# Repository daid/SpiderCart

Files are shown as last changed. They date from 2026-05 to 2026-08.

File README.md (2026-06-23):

# SpiderCart

SpiderCart is a new gameboy and gameboy color flash cartridge. Which will have many legs over the alternatives.

Currently, it is still in development. But it uses a different setup compared to other flash carts. Other carts use FPGAs or CPLDs. Instead the SpiderCart uses a single RP2354B microcontroller to function as the MBC and handle all other functionalities required. This offers greater flexiblity at lower costs.

The SpiderCart is fully open source MIT license. And can be produced and copied by anyone. It also has all the flexibility to be modified by anyone.

## Terminology

This repository documents the technical side of the SpiderCart. Because of this it uses a lot of terminology. This list ensures that we all speak the same language.

* DMG: The origonal grey brick gameboy. With 4 "green" colors.
* GBC: The Gameboy Color. Upgraded version of the grey brick with color support, double CPU speed and a few more things.
* MCU: Microcontroller. In this case the RP2354B from Raspberry Pi. The RP2354B is a RP2350 with internal flash, so references to RP2350 are also refering to this chip.
* SRAM: "Save" ram. This is also called "external ram" from the gameboy perspective, and contained within the cartridge. Optionally this is preserved between power cycles. Not to be confused with "Static RAM" which is a name of a specific type of RAM chips (to which we just refer as RAM chip)
* RTC: A clock. The gameboy documentation usually refers to this as the Timer. It keep "clock"/"wall" time. Even when the gameboy is off. This requires a battery to preserve state.
* Firmware: Code installed on the MCU that facilitates the operation of the flash cart
* Loader: The code running on the gameboy that allows selecting of rom files and potentially do other things.

## Features

The following features are working:

* Support running DMG and GBC roms up to 2MB in size (V1 limitation, design supports up to 8MB)
* Saves backed up to SD card automatically
* Menu to load ROMs from SD card
* Directly loading ROMs through the USB port for quick ROM debugging/testing
* Optional quickboot to start a rom without resetting and running the bootrom (not compatible with all roms)

The following features are in development:

* Pico-8 support
* USB port direct access to SD card for easy file updating without taking out the SD card
* Full support for RTC (Harvest Moon / Pokemon / Homebrew)
* 3 axis accelerometer (Kirby's Tilt 'n' Tumble / Homebrew)
* Rumble support

The following features are ideas that could work but not actively being developed right now:

* Customizable loader to make rom selection look how you want it, current loader is ugly but functional
* SD file access for homebrew
* USB networking
* NES emulation
* Doom

## Implementation

The SpiderCart is implemented by connecting the MCU and RAM chip directly to the gameboy cartridge bus. The RAM chip is loaded with whatever ROM needs to run. The rom is loaded by the MCU into the RAM chip, this can be done while the gameboy is kept in reset.

While the gameboy is running, the MCU needs to act like the MBC, controlling when the RAM chip is enabled, as well as simulating the SRAM. It will only need of the two CPU cores this MCU has, so 1 will be available for other functionality.

On the 150Mhz RP2350 Core1 is constantly running as MBC, while core0 handles things like saving SRAM and communicating with the RTC/Accelerometer/USB.

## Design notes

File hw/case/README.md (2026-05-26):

https://www.printables.com/model/215698-gameboy-cartridge

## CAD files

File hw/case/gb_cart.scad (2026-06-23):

// Gameboy Cartridge
//
// By: Dave Parker https://www.printables.com/social/175295-dave/about
//
// Print with build plate supports, 0.2mm layer height
//

include <BOSL/shapes.scad> // https://github.com/revarbat/BOSL

$fa = 1;
$fs = .1;
ff = 0.001; // fudge factor

width = 57;
depth = 64.8;

classic = false; // Whether to include a logo area on the top half

// fit test with top and bottom interlocking
// translate([0, 0, total_top_height + bottom_base_height + 1.8 ])rotate([0, 180, 0]) top();
// bottom();

// normal rendering
translate([-width/2 - 1, 0, 0]) top();
translate([width/2 + 1, 0, 0]) bottom();

translate([width/2 + 1, depth/2-0.7, 1.6]) % color("#ff000080") import("../pcb/SpiderCart.stl");
translate([-width/2 - 1, depth/2-0.7, 5.8]) rotate([0,180,0]) % color("#ff000080") import("../pcb/SpiderCart.stl");

//translate([-width/2 - 1, 0, 0]) color("#ff00ff") label_cutout();


// BOTTOM HALF /////////////////////////////////////////////////////////////////

alignment_post_height = 2;
alignment_post_r = 0.9;
alignment_post_y = 41.9;

bottom_base_height = 1.4;
bottom_wall_thickness = 1.8;
bottom_wall_height = 4.3;

far_notch_width = 2.5;
far_notch_depth = 1.2;
far_notch_height = 2.5;

groove_height = 1.4;
groove_width = 1.4;

lock_depth = 3;
lock_height = 3;
lock_travel = 2;
lock_width = 1;
lock_y_near = 11;
lock_y_far = 50;

pcb_screw_post_height = 1.6;
pcb_screw_post_r = 3.7;

ridge_depth = 0.8;
ridge_height = 0.2;
ridge_width = 50;

screw_head_height = 2;
screw_head_radius = 3.0;
screw_hole_passthrough_r = 2.0;
screw_y = 17;

type_notch_depth = 3;
type_notch_width = 5;

groove_depth = lock_y_near;
lock_entrance_height = bottom_wall_height - lock_height;
total_bottom_base_height = bottom_base_height + bottom_wall_height;

module usb_hole() {
    cube([10, 10, 4], center=true);
    rotate([90,0,0]) linear_extrude(7, center=true) hull() {
        translate([ 4,-1.5]) circle(2);
        translate([-4,-1.5]) circle(2);
        translate([ 4, 1.5]) circle(2);
        translate([-4, 1.5]) circle(2);
    }
}

module bottom() {

    difference() { 
        union() {
            bottom_base();
            bottom_far_wall();
            bottom_right_wall();
            bottom_left_wall();
        }
        
        if(classic) {
            bottom_grip(classic_grip_y, classic_grip_count);
        } else {
            bottom_grip(grip_y, grip_count);
        }
        translate([-18, 67, 4]) usb_hole();
        translate([-2, 67, 4]) cube([14, 10, 4.0], center=true);
    }
}


module bottom_base() {
    
    difference() { 
        union() {
            
            // Base minus notch at far end
            translate([-width/2, 0, 0])
                cuboid([width, depth - type_notch_depth + ff, bottom_base_height], fillet=0.5,
                    edges=EDGE_BK_RT+EDGE_BOT_LF+EDGE_BOT_RT, center=false);

            // Bit shorter at far end due to type notch
            translate([-width/2, depth - type_notch_depth - ff, 0])
                      cuboid([width - type_notch_width, type_notch_depth, bottom_base_height], fillet=0.5,
                      edges=EDGE_BK_RT+EDGE_BK_LF+EDGE_BOT_LF+EDGE_BOT_BK+EDGE_BOT_RT, center=false);
            
            // Ridge along inside bottom
            translate([-ridge_width/2, 0, bottom_base_height - ff])
                cube([ridge_width, ridge_depth, ridge_height]);
            
            // PCB screw post
            translate([0, screw_y, bottom_base_height - ff])
                cylinder(h=pcb_screw_post_height, r=pcb_screw_post_r);
            
            // Alignment post
            translate([0, alignment_post_y, bottom_base_height - ff])
                cylinder(h=alignment_post_height, r=alignment_post_r);
        }

        side_groove();  // Right
        mirror([-1, 0, 0]) side_groove(); // Left
        
        // Screw shaft hole
        translate([0, screw_y, - ff])
            cylinder(h=bottom_base_height + pcb_screw_post_height + ff*2, r=screw_hole_passthrough_r);

        // Screw thread hole
        translate([0, screw_y, - ff])
            cylinder(h=screw_head_height + ff*2, r=screw_head_radius);

    }
}


module bottom_grip(y, count) {
    
    for(i=[1:1:count]) {
        
        dy = y + i*(grip_thickness + grip_spacing);

         translate([-width/2 - ff, dy, - ff])
             cube([grip_side_depth, grip_thickness, total_bottom_base_height  + ff*2]);
        
         translate([width/2 - grip_side_depth + ff , dy, - ff])
             cube([grip_side_depth, grip_thickness, total_bottom_base_height + ff*2]);
    }
}


module side_groove() {
    translate([ridge_width/2, - ff, groove_height/2 + ff]) 
        cube([groove_width, groove_depth, groove_height/2 + ff*2]);
}


module bottom_right_wall() {  

    difference() {
        union() {
            translate([width/2 - bottom_wall_thickness, 0, bottom_base_height - ff])
                cuboid([bottom_wall_thickness, depth - type_notch_depth, bottom_wall_height],
                        fillet=0.5, edges=EDGE_BK_RT, center=false);

            bottom_wall_common_additive();
        }

        bottom_wall_common_subtractive();
    }
}


module bottom_left_wall() {  

    difference() {
        union() {
            translate([-width/2, 0, bottom_base_height - ff])
                cube([bottom_wall_thickness, depth - bottom_wall_thickness + ff, bottom_wall_height]);
            
            mirror([-1, 0, 0]) bottom_wall_common_additive();
        }
        
        mirror([-1, 0, 0]) bottom_wall_common_subtractive();
    }
}


module bottom_wall_common_additive() {
    
    dx = width/2 - bottom_wall_thickness - (ridge_width/2 + groove_width) + ff;
    translate([ridge_width/2 + groove_width, 0, bottom_base_height - ff])
        cube([dx, groove_depth, bottom_wall_height]);
}


module bottom_wall_common_subtractive() {
    lock(lock_y_near);
    lock(lock_y_far);
}


module lock(y) {
    
    // Entrance
    translate([width/2 - bottom_wall_thickness - ff, y, bottom_base_height - ff])
        cube([lock_width, lock_depth, bottom_wall_height + ff*2]);
    
    // Travel
    translate([width/2 - bottom_wall_thickness - ff, y + lock_depth - ff, bottom_base_height - ff])
        cube([lock_width, lock_travel, lock_height + ff*2]); 
}


module bottom_far_wall() {
    
    difference() {
        // Far wall
        translate([-width/2, depth - bottom_wall_thickness, bottom_base_height - ff])
            cuboid([width - type_notch_width, bottom_wall_thickness, bottom_wall_height],
            fillet=0.5, edges=EDGE_BK_LF+EDGE_BK_RT, center=false);
        
        // Far wall notch
        translate([-far_notch_width/2, depth - bottom_wall_thickness - ff, bottom_base_height - ff])
            cube([far_notch_width, far_notch_depth, far_notch_height]);
    }
 
    // Mode notch horizontal wall
    translate([width/2 - bottom_wall_thickness - type_notch_width + ff,
              depth - bottom_wall_thickness - type_notch_depth,
              bottom_base_height - ff])
        cube([type_notch_width, bottom_wall_thickness,  bottom_wall_height]);
    
    // Mode notch vertical wall
    translate([width/2 - bottom_wall_thickness - type_notch_width + ff,
              depth - bottom_wall_thickness - type_notch_depth,
              bottom_base_height - ff])
        cube([bottom_wall_thickness, type_notch_depth,  bottom_wall_height]);
}


// TOP HALF /////////////////////////////////////////////////////////////////////

far_tab_width = far_notch_width - 0.5;
far_tab_depth = far_notch_depth - 0.2;
far_tab_height = far_notch_height/2; 

classic_grip_count = 5;

grip_count = 6;
grip_side_depth = 0.3;
grip_top_depth = 0.6;
grip_thickness = 1;
grip_spacing = 1;

key_depth = lock_depth - 1;
key_width = lock_width - 0.2;

label_depth = 39;
label_height = 0.2;
label_y = 8;
label_width = 44;

logo_depth = 12;
logo_height = 0.6;
logo_width = 44;
logo_y = label_y + label_depth + 2;

screw_height = 3;
screw_hole_thread_r = 1.45;
screw_shaft_r = 3;

side_tab_y = 32;
side_tab_width = 1.5;
side_tab_depth = 1;

top_angle_cut_depth = 37.7;
top_height = 2;
top_inner_height = 1.3;
top_near_wall_y = 10;
top_wall_height = 3.8;
top_wall_thickness = 1.5;

wall_gap = 0.4; // Padding between top and bottom walls

grip_y = label_y + label_depth;
classic_grip_y = grip_y + 1.5;
key_height = top_wall_height - lock_entrance_height - 0.75;
total_top_height = top_height - top_inner_height + top_wall_height;
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

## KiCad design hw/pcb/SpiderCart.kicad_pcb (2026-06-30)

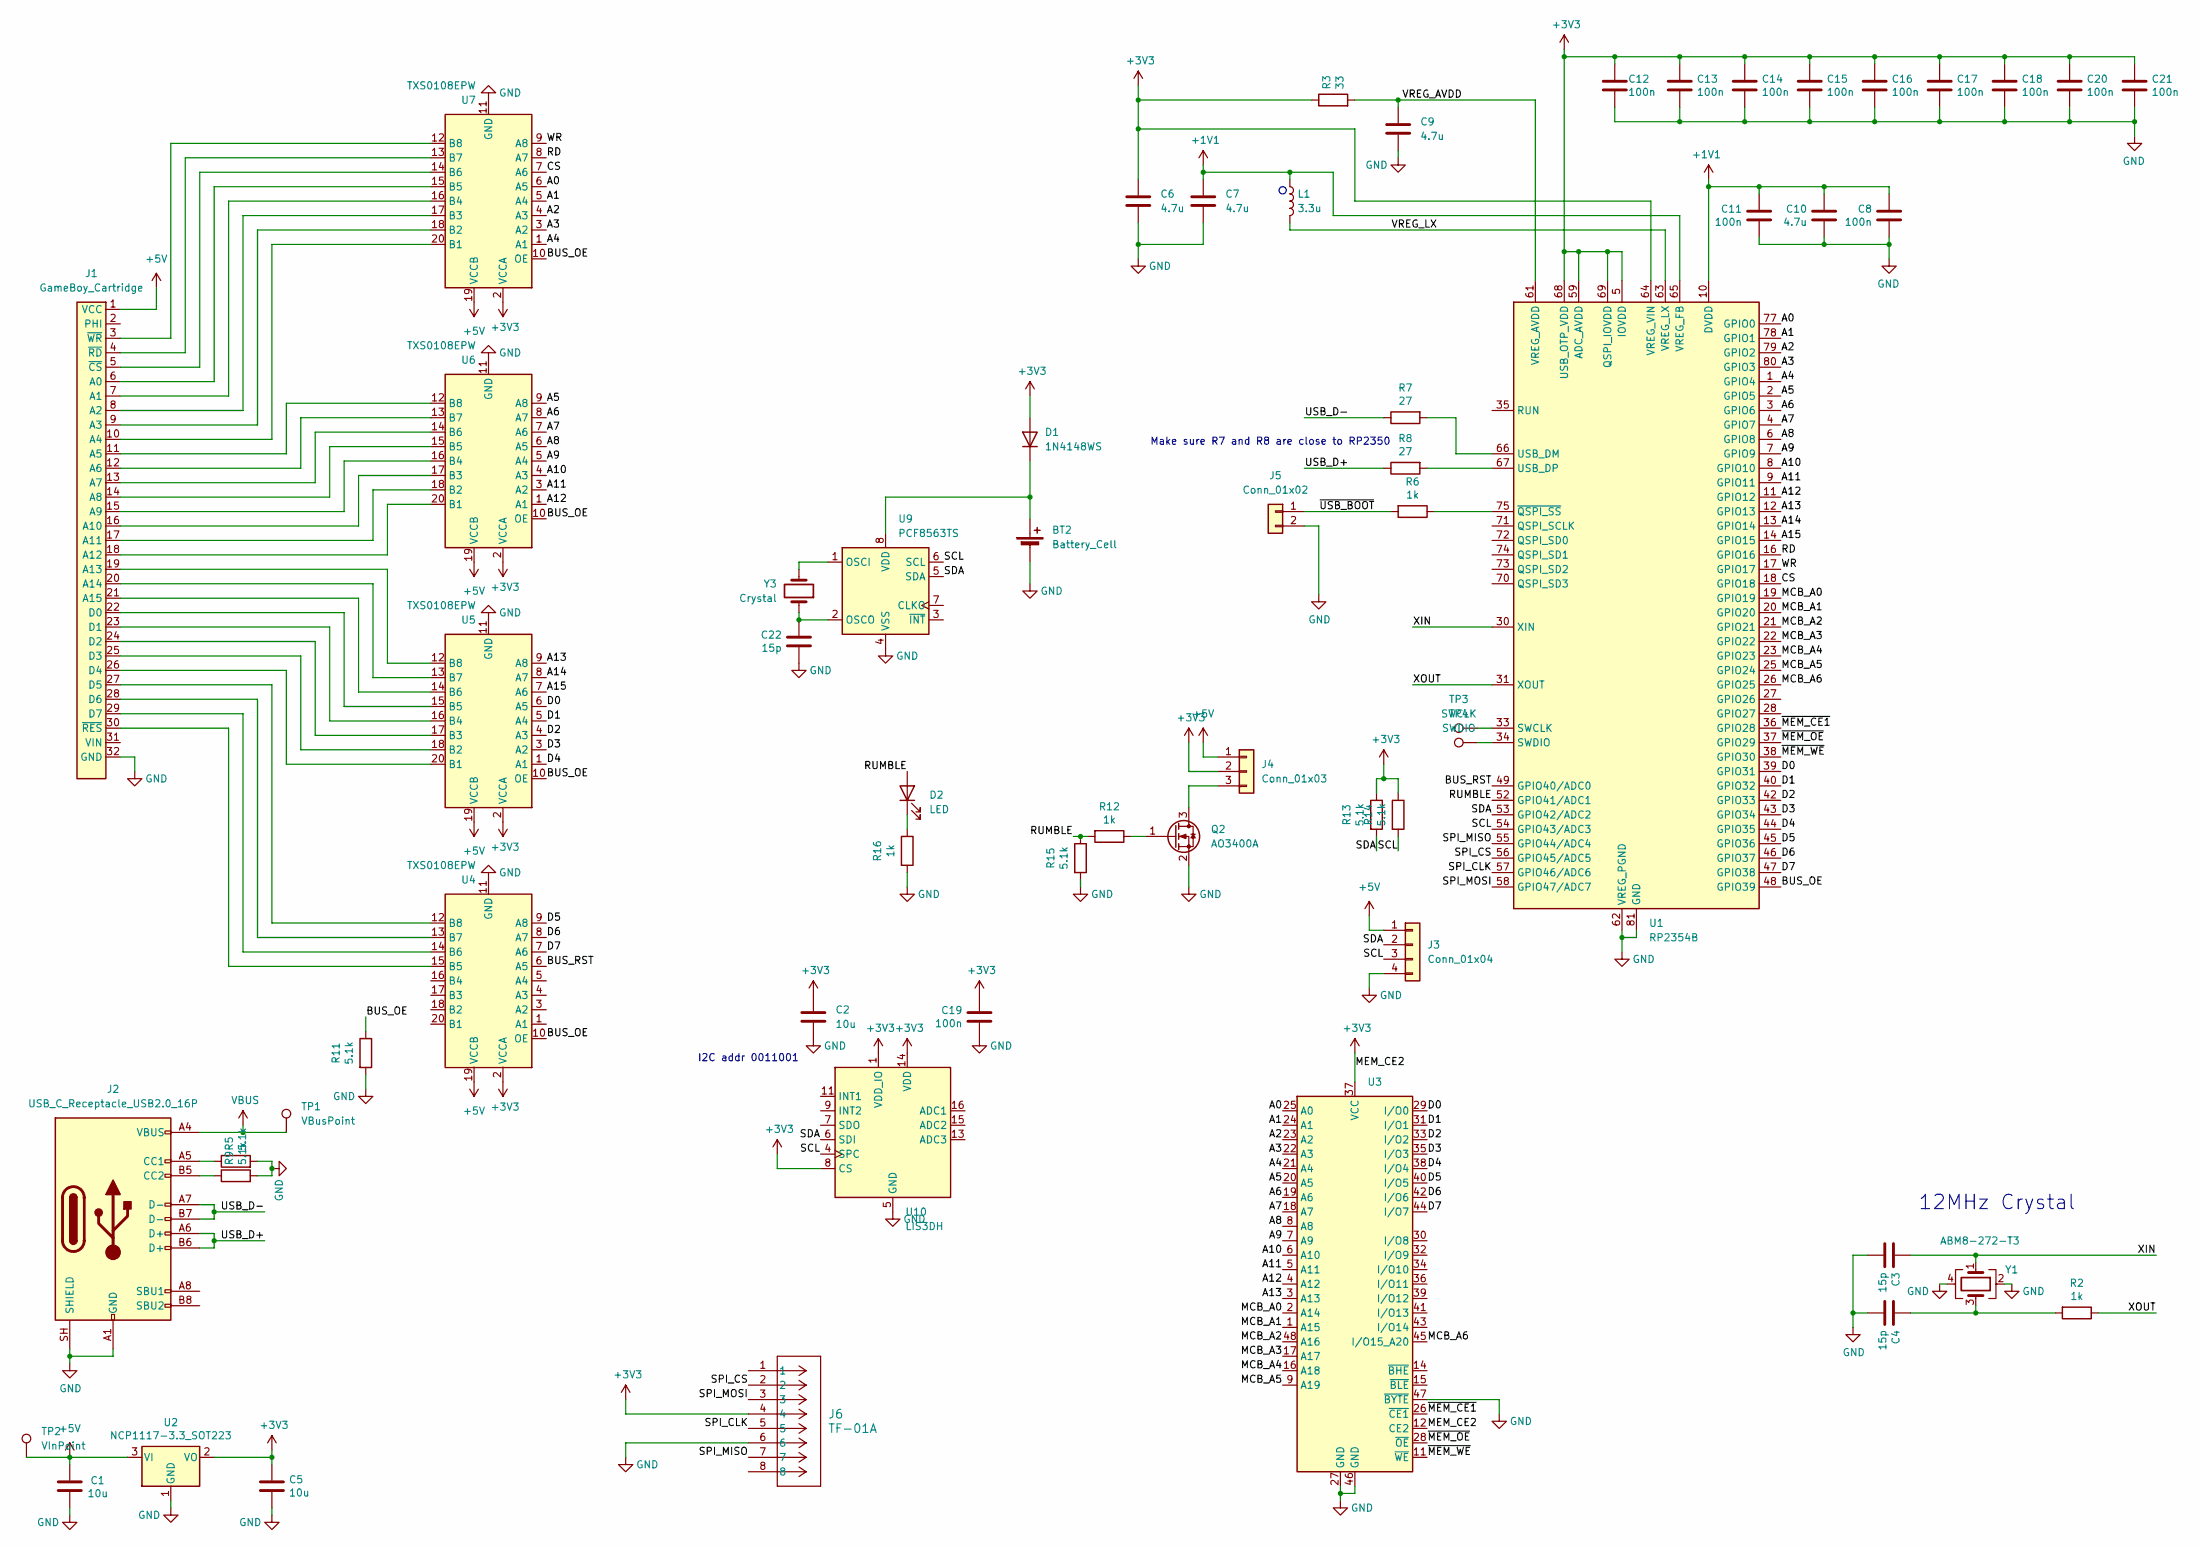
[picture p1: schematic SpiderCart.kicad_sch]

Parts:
BT2: Battery_Cell; BatteryHolder_Keystone_2998_1x6.8mm
C1, C5: 10u; C_0805_2012Metric
C2: 10u; C_0402_1005Metric
C3, C4, C22: 15p; C_0402_1005Metric
C6, C7: 4.7u; C_0402_1005Metric_small_pads
C8, C11, C12, C13, C14, C15, C16, C17, C18, C19, C20, C21: 100n; C_0402_1005Metric
C9, C10: 4.7u; C_0402_1005Metric
D1: 1N4148WS; D_SOD-323
D2: LED; LED_0603_1608Metric
J1: GameBoy_Cartridge; GameBoy_Cartridge_1x32_P1.50mm_Edge
J2: USB_C_Receptacle_USB2.0_16P; USB_C_Receptacle_JAE_DX07S016JA1R1500
J3: Conn_01x04; PinHeader_1x04_P1.27mm_Vertical
J4: Conn_01x03; PinHeader_1x03_P1.27mm_Vertical
J5: Conn_01x02; PinSocket_1x02_P1.27mm_Vertical
J6: TF-01A; CONN_TF-01A_HRO
L1: 3.3u; L_pol_2016
Q2: AO3400A; SOT-23
R2, R6, R12, R16: 1k; R_0402_1005Metric
R3: 33; R_0402_1005Metric
R5, R9, R11, R13, R14, R15: 5.1k; R_0402_1005Metric
R7, R8: 27; R_0402_1005Metric
TP1: VBusPoint; PinHeader_1x01_P1.27mm_Vertical
TP2: VInPoint; PinHeader_1x01_P1.27mm_Vertical
TP3: SWCLK; TestPoint_Pad_D1.5mm
TP4: SWDIO; TestPoint_Pad_D1.5mm
U1: RP2354B; QFN-80-1EP_10x10mm_P0.4mm_EP3.4x3.4mm_ThermalVias
U2: NCP1117-3.3_SOT223; SOT-223-3_TabPin2
U3: TSOP-I-48_18.4x12mm_P0.5mm
U4, U5, U6, U7: TXS0108EPW; TSSOP-20_4.4x6.5mm_P0.65mm
U9: PCF8563TS; MSOP-8_3x3mm_P0.65mm
U10: LIS3DH; LGA-16_3x3mm_P0.5mm_LayoutBorder3x5y
Y1: ABM8-272-T3; Crystal_SMD_3225-4Pin_3.2x2.5mm
Y3: Crystal; Crystal_SMD_3215-2Pin_3.2x1.5mm

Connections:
+1V1: C7.1, C8.1, C10.1, C11.1, L1.1, U1.10 (DVDD), U1.32 (DVDD), U1.51 (DVDD), U1.65 (VREG_FB)
+3V3: C2.1, C5.1, C6.1, C12.1, C13.1, C14.1, C15.1, C16.1, C17.1, C18.1, C19.1, C20.1, C21.1, D1.2 (A), J4.2, J6.4, R3.1, R13.1, R14.1, U1.5 (IOVDD), U1.15 (IOVDD), U1.24 (IOVDD), U1.29 (IOVDD), U1.41 (IOVDD), U1.50 (IOVDD), U1.59 (ADC_AVDD), U1.60 (IOVDD), U1.64 (VREG_VIN), U1.68 (USB_OTP_VDD), U1.69 (QSPI_IOVDD), U1.76 (IOVDD), U2.2 (VO), U3.12 (CE2), U3.37 (VCC), U4.2 (VCCA), U5.2 (VCCA), U6.2 (VCCA), U7.2 (VCCA), U10.1 (VDD_IO), U10.8 (CS), U10.14 (VDD)
+5V: C1.1, J1.1 (VCC), J3.1, J4.1, TP2.1 (1_1), U2.3 (VI), U4.19 (VCCB), U5.19 (VCCB), U6.19 (VCCB), U7.19 (VCCB)
/A0: U1.77 (GPIO0), U3.25 (A0), U7.6 (A5)
/A1: U1.78 (GPIO1), U3.24 (A1), U7.5 (A4)
/A2: U1.79 (GPIO2), U3.23 (A2), U7.4 (A3)
/A3: U1.80 (GPIO3), U3.22 (A3), U7.3 (A2)
/A4: U1.1 (GPIO4), U3.21 (A4), U7.1 (A1)
/A5: U1.2 (GPIO5), U3.20 (A5), U6.9 (A8)
/A6: U1.3 (GPIO6), U3.19 (A6), U6.8 (A7)
/A7: U1.4 (GPIO7), U3.18 (A7), U6.7 (A6)
/A8: U1.6 (GPIO8), U3.8 (A8), U6.6 (A5)
/A9: U1.7 (GPIO9), U3.7 (A9), U6.5 (A4)
/A10: U1.8 (GPIO10), U3.6 (A10), U6.4 (A3)
/A11: U1.9 (GPIO11), U3.5 (A11), U6.3 (A2)
/A12: U1.11 (GPIO12), U3.4 (A12), U6.1 (A1)
/A13: U1.12 (GPIO13), U3.3 (A13), U5.9 (A8)
/A14: U1.13 (GPIO14), U5.8 (A7)
/A15: U1.14 (GPIO15), U5.7 (A6)
/BUS_OE: R11.1, U1.48 (GPIO39), U4.10 (OE), U5.10 (OE), U6.10 (OE), U7.10 (OE)
/BUS_RST: U1.49 (GPIO40/ADC0), U4.6 (A5)
/CS: U1.18 (GPIO18), U7.7 (A6)
/D0: U1.39 (GPIO31), U3.29 (I/O0), U5.6 (A5)
/D1: U1.40 (GPIO32), U3.31 (I/O1), U5.5 (A4)
/D2: U1.42 (GPIO33), U3.33 (I/O2), U5.4 (A3)
/D3: U1.43 (GPIO34), U3.35 (I/O3), U5.3 (A2)
/D4: U1.44 (GPIO35), U3.38 (I/O4), U5.1 (A1)
/D5: U1.45 (GPIO36), U3.40 (I/O5), U4.9 (A8)
/D6: U1.46 (GPIO37), U3.42 (I/O6), U4.8 (A7)
/D7: U1.47 (GPIO38), U3.44 (I/O7), U4.7 (A6)
/MCB_A0: U1.19 (GPIO19), U3.2 (A14)
/MCB_A1: U1.20 (GPIO20), U3.1 (A15)
/MCB_A2: U1.21 (GPIO21), U3.48 (A16)
/MCB_A3: U1.22 (GPIO22), U3.17 (A17)
/MCB_A4: U1.23 (GPIO23), U3.16 (A18)
/MCB_A5: U1.25 (GPIO24), U3.9 (A19)
/MCB_A6: U1.26 (GPIO25), U3.45 (I/O15_A20)
/RD: U1.16 (GPIO16), U7.8 (A7)
/RUMBLE: D2.2 (A), R12.2, R15.1, U1.52 (GPIO41/ADC1)
/SCL: J3.3, R14.2, U1.54 (GPIO43/ADC3), U9.6 (SCL), U10.4 (SPC)
/SDA: J3.2, R13.2, U1.53 (GPIO42/ADC2), U9.5 (SDA), U10.6 (SDI)
/SPI_CLK: J6.5, U1.57 (GPIO46/ADC6)
/SPI_CS: J6.2, U1.56 (GPIO45/ADC5)
/SPI_MISO: J6.7, U1.55 (GPIO44/ADC4)
/SPI_MOSI: J6.3, U1.58 (GPIO47/ADC7)
/USB_D+: J2.A6 (D+), J2.B6 (D+), R8.1
/USB_D-: J2.A7 (D-), J2.B7 (D-), R7.1
/VREG_AVDD: C9.1, R3.2, U1.61 (VREG_AVDD)
/VREG_LX: L1.2, U1.63 (VREG_LX)
/WR: U1.17 (GPIO17), U7.9 (A8)
/XIN: C3.1, U1.30 (XIN), Y1.1
/XOUT: R2.1, U1.31 (XOUT)
/~MEM_CE1: U1.36 (GPIO28), U3.26 (~CE1)
/~MEM_OE: U1.37 (GPIO29), U3.28 (~OE)
/~MEM_WE: U1.38 (GPIO30), U3.11 (~WE)
/~USB_BOOT: J5.1, R6.2
GND: BT2.2 (-), C1.2, C2.2, C3.2, C4.2, C5.2, C6.2, C7.2, C8.2, C9.2, C10.2, C11.2, C12.2, C13.2, C14.2, C15.2, C16.2, C17.2, C18.2, C19.2, C20.2, C21.2, C22.2, J1.32 (GND), J2.A1 (GND), J2.A12 (GND), J2.B1 (GND), J2.B12 (GND), J2.SH (SHIELD), J3.4, J5.2, J6.6, Q2.2 (S), R5.2, R9.2, R11.2, R15.2, R16.2, U1.62 (VREG_PGND), U1.81 (GND), U2.1 (GND), U3.27 (GND), U3.46 (GND), U3.47 (~BYTE), U4.11 (GND), U5.11 (GND), U6.11 (GND), U7.11 (GND), U9.4 (VSS), U10.5 (GND), U10.10 (GND), U10.12 (GND), Y1.2, Y1.4
unnamed: BT2.1 (+), D1.1 (K), U9.8 (VDD)
unnamed: C4.1, R2.2, Y1.3
unnamed: D2.1 (K), R16.1
unnamed: J1.6 (A0), U7.15 (B5)
unnamed: J1.7 (A1), U7.16 (B4)
unnamed: J1.8 (A2), U7.17 (B3)
unnamed: J1.9 (A3), U7.18 (B2)
unnamed: J1.10 (A4), U7.20 (B1)
unnamed: J1.11 (A5), U6.12 (B8)
unnamed: J1.12 (A6), U6.13 (B7)
unnamed: J1.13 (A7), U6.14 (B6)
unnamed: J1.14 (A8), U6.15 (B5)
unnamed: J1.15 (A9), U6.16 (B4)
unnamed: J1.16 (A10), U6.17 (B3)
unnamed: J1.17 (A11), U6.18 (B2)
unnamed: J1.18 (A12), U6.20 (B1)
unnamed: J1.19 (A13), U5.12 (B8)
unnamed: J1.20 (A14), U5.13 (B7)
unnamed: J1.21 (A15), U5.14 (B6)
unnamed: J1.22 (D0), U5.15 (B5)
unnamed: J1.23 (D1), U5.16 (B4)
unnamed: J1.24 (D2), U5.17 (B3)
unnamed: J1.25 (D3), U5.18 (B2)
unnamed: J1.26 (D4), U5.20 (B1)
unnamed: J1.27 (D5), U4.12 (B8)
unnamed: J1.28 (D6), U4.13 (B7)
unnamed: J1.29 (D7), U4.14 (B6)
unnamed: J1.5 (~CS), U7.14 (B6)
unnamed: J1.4 (~RD), U7.13 (B7)
unnamed: J1.30 (~RES), U4.15 (B5)
unnamed: J1.3 (~WR), U7.12 (B8)
unnamed: J2.A5 (CC1), R5.1
unnamed: J2.B5 (CC2), R9.1
unnamed: J4.3, Q2.3 (D)
unnamed: Q2.1 (G), R12.1
unnamed: TP3.1 (1_1), U1.33 (SWCLK)
unnamed: TP4.1 (1_1), U1.34 (SWDIO)
unnamed: R7.2, U1.66 (USB_DM)
unnamed: R8.2, U1.67 (USB_DP)
unnamed: R6.1, U1.75 (~QSPI_SS)
unnamed: U9.1 (OSCI), Y3.2
unnamed: C22.1, U9.2 (OSCO), Y3.1
VBUS: J2.A4 (VBUS), J2.A9 (VBUS), J2.B4 (VBUS), J2.B9 (VBUS), TP1.1 (1_1)

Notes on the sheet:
12MHz Crystal
Make sure R7 and R8 are close to RP2350
I2C addr 0011001

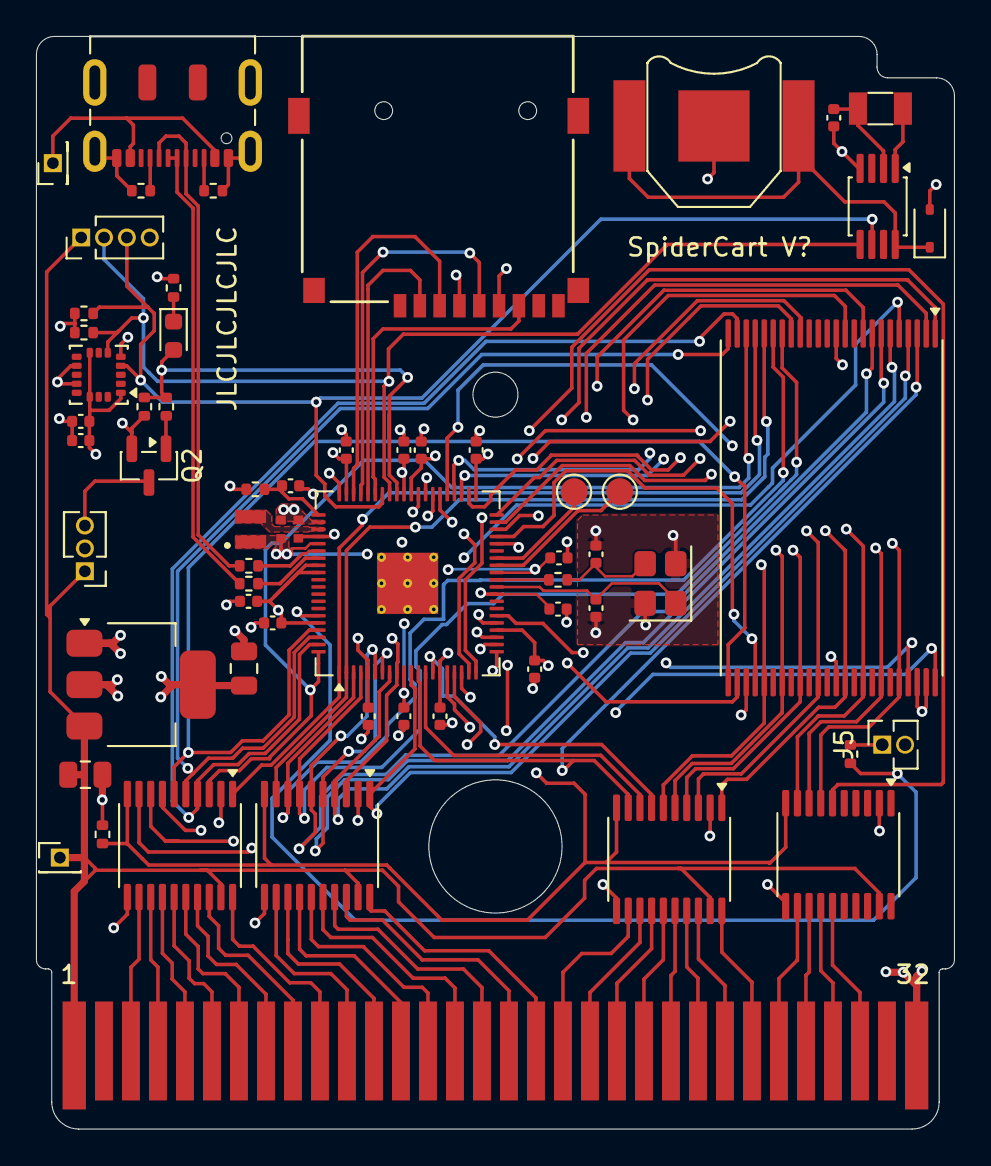
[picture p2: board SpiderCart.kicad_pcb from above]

Board: 4 copper layers, 51.0 x 60.7 mm, 61 parts (0 on the bottom side), 100 nets.

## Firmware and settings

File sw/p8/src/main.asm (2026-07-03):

#INCLUDE "gbz80/all.asm"
#INCLUDE "gbz80/extra/if.asm"
#INCLUDE "gbz80/extra/loop.asm"
#INCLUDE "gbz80/extra/ld16.asm"
#INCLUDE "gbz80/extra/pushpop.asm"

#INCLUDE "video.asm"
#INCLUDE "input.asm"
#INCLUDE "copy.asm"

#INCSDCC "config.rel"

GBC_HEADER "SpiderCart", GB_MBC5_RAM, entry

#SECTION "SpiderCartIndicator", ROM0[$150] {
    ; Most ROMs have the entry directly after the header. For a SpiderCart compatible ROM
    ; We put a special indicator here to indicate to the cart should run with special features enabled
    db $DD ; Indicator 1, this is an invalid instruction.
    db "SPIDER"
}

#SECTION "HRAM", HRAM {
hLCDC: ds 1
hVBlankDone: ds 1
hGBC: ds 1
}

#MACRO POPSLIDE {
    ld  [hl+],a
    ld  a, d
    ld  [hl+], a
    pop de
    ld  a, e
}

#MACRO HALT_FOR _FLAG {
    ld   a, _FLAG
    ldh  [rIE], a
    xor  a
    ldh  [rIF], a
    ld   a, e ; prepare for popslide
    halt
    nop
}

#MACRO WAIT_HBLANK {
:   ldh a, [rSTAT]
    and a, STAT_MODE_MASK
    jr  nz, :- ; != STAT_HBLANK
}

#MACRO WAIT_VBLANK {
:   ldh a, [rSTAT]
    and a, STAT_MODE_MASK
    cp  STAT_VBLANK
    jr  nz, :-
}

#SECTION "Entry", ROM0 {
entry:
    cp   a, $11
    jr   z, .gbc
    xor  a
.gbc:
    ldh  [hGBC], a
    ld   sp, $E000

    call lcd_off
    ld   hl, $8000
    ld   bc, $2000
    call clearMem

    ld   hl, fontData
    ld   de, $9000
    ld   bc, fontData.end - fontData
    call copy1BPP

    ld   de, $9800 - (fullTiles.end - fullTiles)
    ld   hl, fullTiles
    ld   bc, fullTiles.end - fullTiles
    call copyMem

    ; Enable SRAM and switch to bank 15
    ld   a, $0A
    ld   [$0000], a
    ld   a, $0F
    ld   [$4000], a

    ld   hl, $A000
    ld   de, $8000
    ld   bc, 16 * 16 * 16
    call copyMem ; Copy initial screen

    ldh  a, [hGBC]
    and  a, a
    if   nz {
        ld   a, 1
        ldh  [rVBK], a
        ; Set all tiles to 2nd VRAM bank except for the 128x128 render area
        ld   hl, $9800
        ld   bc, $0400
        ld   a, $08
        call setMem

        ld   a, 01 ; use pal 1 for visible area tiles
        ld   hl, $9800
        loop b, 16 {
            loop c, 16 {
                ld   [hl+], a
            }
            ld  de, 16
            add hl, de
        }
        xor  a
        ldh  [rVBK], a

    } else {
        ld   a, %00_00_00_00
        ldh  [rBGP], a
        ldh  [rOBP0], a
        ldh  [rOBP1], a
    }

    ; Center the view screen
    ld   a, -16
    ldh  [rSCX], a
    ld   a, -8
    ldh  [rSCY], a

    ; Setup the tile indexes for the render area
    ld   a, 00
    ld   hl, $9800
    loop b, 16 {
        loop c, 16 {
            ld   [hl+], a
            inc  a
        }
        ld  de, 16
        add hl, de
    }
    ; Clear the 2nd tilemap
    ld   hl, $9C00
    ld   bc, $0400
    ld   a, $00
    call setMem
    ; Prepare audio
    ld   a, $8F
    ldh  [rNR52], a
    ld   a, $FF
    ldh  [rNR51], a
    ld   a, $77
    ldh  [rNR50], a

    ldh  a, [hGBC]
    and  a, a
    jp   z, .startDMG

    ld   a, LCDC_ON | LCDC_WIN_9C00 | LCDC_BG_ON | LCDC_BLOCK01
    ldh  [hLCDC], a
    ldh  [rLCDC], a
    call waitVBlank

    ld   hl, defaultPalette
    ld   de, wBGPalette
    ld   bc, 8 * 4 * 2
    call copyMem
    call setBGPalette

.loopGBC:
    call updateJoypadState
    ld   a, [wJoypadState]
    ld   [$A000 + $1FF0], a
    ld   a, [wJoypadPressed]
    and  a, PADF_START
    call nz, configScreen
    ld   a, $80 ; COMMAND_P8_CYCLE_60
    ld   [$6000], a
    
    ; ; Wait for VBLank
    call waitVBlank
    
    ; Copy 128 tiles with HDMA in direct copy
    ld   a, $A0
    ldh  [rHDMA1], a
    ld   a, $00
    ldh  [rHDMA2], a
    ld   a, $80
    ldh  [rHDMA3], a
    ld   a, $00
    ldh  [rHDMA4], a
    ld   a, 127
    ldh  [rHDMA5], a
    ; Now we are nearing end of VBlank, so copy the rest in HBlank
    ld   a, 127 | $80
    ldh  [rHDMA5], a

    ld   hl, $BD00
    ld   e, [hl] ; active sound flags
    inc  hl
    bit  0, e
    if   nz {
        ld  a, [hl+]
        ldh [rNR10], a
        ld  a, [hl+]
        ldh [rNR11], a
        ld  a, [hl+]
        ldh [rNR12], a
        ld  a, [hl+]
        ldh [rNR13], a
        ld  a, [hl+]
        ldh [rNR14], a
    } else {
        ld  a, 5
        add a, l
        ld  l, a
    }
    bit  1, e
    if   nz {
        ld  a, [hl+]
        ldh [rNR21], a
        ld  a, [hl+]
        ldh [rNR22], a
        ld  a, [hl+]
        ldh [rNR23], a
        ld  a, [hl+]
        ldh [rNR24], a
    } else {
        ld  a, 4
        add a, l
        ld  l, a
    }

    ; Check for errors
    ld   a, [$BFFF]
    and  a, a
    jp   nz, displayError

    jr .loopGBC

.startDMG:
    ld   a, STAT_MODE_0
    ldh  [rSTAT], a

    ld   a, $01
    ld   hl, $9830
    loop c, 16 {
        loop b, 16 {
            ld   [hl+], a
        }
        ld  de, 48
        add hl, de
    }

    ld   hl, dmgOAM
    ld   de, $FE00
    ld   bc, 40 * 4
    call copyMem

    ld   a, LCDC_ON | LCDC_WIN_9C00 | LCDC_BG_ON | LCDC_BLOCK01 | LCDC_OBJ_ON | LCDC_OBJ_16
    ldh  [hLCDC], a
    ldh  [rLCDC], a

    call waitVBlank
.loopDMG:
    call updateJoypadState
    ld   a, [wJoypadState]
    ld   [$A000 + $1FF0], a
    ld   a, $81 ; COMMAND_P8_CYCLE_30
    ld   [$6000], a

    ld   sp, $A000
    ld   hl, $8000
    pop  de

    ; This code is tuned to copy exactly 128 tiles per frame in VBlank and HBlank time.
    #FOR FRAME_LOOP, 0, 2 {    
        HALT_FOR IE_VBLANK
        ld   a, e
        #FOR n, 0, 93 {
            POPSLIDE
        }
        ; There is a bit of spare time here.
        loop c, 7 {
            HALT_FOR IE_STAT
            #FOR n, 0, 6 {
                POPSLIDE
            }
        }
        HALT_FOR IE_STAT
        ld   a, %11_10_01_00
        ldh  [rBGP], a
        loop c, 127 {
            HALT_FOR IE_STAT
            #FOR n, 0, 7 {
                POPSLIDE
            }
        }
        HALT_FOR IE_STAT
        ld   a, %00_00_00_00
        ldh  [rBGP], a
        ; We are only at line 136, so we have some spare time till VBlank here.
    }
    ld   sp, $E000

    ; Check for errors
    ld   a, [$BFFF]
    and  a, a
    jp   nz, displayError

    jp .loopDMG

defaultPalette:
    dw $7FFF, $5294, $35ad, $0000
    dw $7FFF, $5294, $35ad, $0000
    dw $FFFF, $0000, $FFFF, $0000
    dw $FFFF, $0000, $FFFF, $0000
_picoColors:
    dw $0000, $34C6, $34B1, $3260
    dw $25D4, $31AE, $5ED6, $6B9F
    dw $301F, $033F, $23FF, $27E0
    dw $7E48, $4DF1, $51FF, $533F

dmgOAM:
    #FOR Y, 0, 8 {
        db Y * 16 + 24, 8, 0, 0
        db Y * 16 + 24, 16, 0, 0
        db Y * 16 + 24, 128 + 24, 0, 0
        db Y * 16 + 24, 128 + 32, 0, 0
    }
    #FOR N, 0, 8 {
        db 0, 0, 0, 0
    }
}

#SECTION "Config", ROM0 {
configScreen:
    call setupTextScreen

    call _configMenu

    call lcd_off
    ldh  a, [hLCDC]
    ldh  [rLCDC], a

    ret

setupTextScreen:
    call lcd_off

    ld   a, 7
    ldh  [rWX], a
    xor  a
    ldh  [rWY], a
    ld   hl, $9C00
    ld   bc, $0400
    call clearMem

    ld   a, LCDC_ON | LCDC_WIN_9C00 | LCDC_WIN_ON | LCDC_BG_ON | LCDC_BLOCK21
    ldh  [rLCDC], a

    ret
}

#SECTION "ErrorDisplay", ROM0 {
displayError:
    call setupTextScreen
    call lcd_off

    ; Copy error message
    ld   de, $BF00
    ld   hl, $9C00
    loop {
        ld   a, [de]
        sub  a, $20
        jr   c, .errorDone
        ld   [hl+], a
        inc  de
        ld   a, l
        and  a, $1F
        cp   20
        if   nc {
            ld  bc, 32 - 20
            add hl, bc
        }
    }

.errorDone:
    ld   a, LCDC_ON | LCDC_WIN_9C00 | LCDC_WIN_ON | LCDC_BG_ON | LCDC_BLOCK21
    ldh  [rLCDC], a

.loop:
    xor  a
    ldh  [rIF], a
    ldh  [rIE], a
    halt
    nop
    jr .loop
}

#SECTION "PrintStr", ROM0 {
_printStr: ; print the string at BC on the background at DE=YX
    ld  h, d
    xor a ; clear carry
    rr  h
    rra
    rr  h
    rra
    rr  h
    rra
    or  e
    ld  l, a
    ld  a, $9C
    add a, h
    ld  h, a

.loop:
    ld  a, [bc]
    sub a, $20
    ret c
    inc bc

    ld  e, a
    STAT_WAIT
    ld  a, e
    ld  [hl+], a
    jr  .loop

_setTileGBC:
    ; set the background tile at DE=YX to BC=tilenr,attr
    ld  h, d
    xor a ; clear carry
    rr  h
    rra
    rr  h
    rra
    rr  h
    rra
    or  e
    ld  l, a
    ld  a, $9C
    add a, h
    ld  h, a

    ld  a, 1
    ldh [rVBK], a
    STAT_WAIT
    ld  [hl], c
    xor a
    ldh [rVBK], a

    STAT_WAIT
    ld  [hl], b

    ret

_clearScreen:
    ldh a, [hGBC]
    and a
    if  nz {
        ld   a, 1
        ldh  [rVBK], a
        call clearScreenImpl
        xor  a
        ldh  [rVBK], a
    }
clearScreenImpl:
    ld  hl, $9C00
    ld  bc, $0400
.loop:
    STAT_WAIT
    ld  [hl+], a ; a is 0 after STAT_WAIT
    dec c
    jr  nz, .loop
    dec b
    jr  nz, .loop
    ret

_startSplitScreen:
    ld   a, 100
    ldh  [rWY], a
    ldh  [rLYC], a
    ld   a, STAT_LYC
    ld   [rSTAT], a
    ld   a, IE_VBLANK | IE_STAT
    ldh  [rIE], a
    ei
    ret

_updateP8Screen:
    ; Copy 128 tiles with HDMA in direct copy
    ld   a, $A0
    ldh  [rHDMA1], a
    ld   a, $00
    ldh  [rHDMA2], a
    ld   a, $80
    ldh  [rHDMA3], a
    ld   a, $00
    ldh  [rHDMA4], a
    ld   a, 127
    ldh  [rHDMA5], a
    ; Now we are nearing end of VBlank, so copy the rest in HBlank
    ld   a, 127 | $80
    ldh  [rHDMA5], a

    ld   a, $82 ; COMMAND_P8_RENDER
    ld   [$6000], a
    ret

_endSplitScreen:
    di
    xor  a
    ldh  [rWY], a
    ld   a, LCDC_ON | LCDC_WIN_9C00 | LCDC_WIN_ON | LCDC_BG_ON | LCDC_BLOCK21
    ldh  [rLCDC], a
    ret
}

#SECTION "VBlankISR", ROM0[$0040] {
VBlankISR:
    jp  VBlankISRImpl
}

#SECTION "VBlankISRImpl", ROM0 {
VBlankISRImpl:
    ldh  a, [hLCDC]
    ldh  [rLCDC], a
    ld   a, 1
    ldh  [hVBlankDone], a
    reti
}

#SECTION "StatISR", ROM0[$0048] {
StatISR:
    pushpop af {
        ld   a, LCDC_ON | LCDC_WIN_9C00 | LCDC_WIN_ON | LCDC_BG_ON | LCDC_BLOCK21
        ldh  [rLCDC], a
    }
    reti
}

#SECTION "Font", ROM0 {
fontData:
    #INCGFX "font.1bpp.png", BPP[1], COLORMAP[$000000, $FFFFFF]
.end:
fullTiles:
    #FOR n, 0, 8 {
        dw $0000
    }
    #FOR n, 0, 8 {
        dw $00FF
    }
    #FOR n, 0, 8 {
        dw $FF00
    }
    #FOR n, 0, 8 {
        dw $FFFF
    }
.end:
}

#SECTION "SRAM", SRAM {
    ; For now ensure we have at least one SRAM section so the header has SRAM marked and BGB won't complain.
}

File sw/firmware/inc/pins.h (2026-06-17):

#pragma once

#define PIN_GB_A0  0
#define PIN_GB_A14 14
#define PIN_GB_A15 15

#define PIN_GB_RD  16
#define PIN_GB_WR  17
#define PIN_GB_CS  18

#define PIN_MBC_A0 19
#define PIN_MBC_A1 20
#define PIN_MBC_A2 21
#define PIN_MBC_A3 22
#define PIN_MBC_A4 23
#define PIN_MBC_A5 24
#define PIN_MBC_A6 25
//MBC_A7 and MBC_A8 are not connected in V1
#define PIN_MBC_A7 26
#define PIN_MBC_A8 27

#define PIN_MEM_CE 28
#define PIN_MEM_OE 29
#define PIN_MEM_WE 30

#define PIN_GB_D0  31
#define PIN_GB_D1  32
#define PIN_GB_D2  33
#define PIN_GB_D3  34
#define PIN_GB_D4  35
#define PIN_GB_D5  36
#define PIN_GB_D6  37
#define PIN_GB_D7  38

#define PIN_BUS_EN 39

#define PIN_GB_RST 40
#define PIN_RUMBLE 41
#define PIN_SDA    42
#define PIN_SCL    43
#define PIN_SD_MISO 44
#define PIN_SD_CS   45
#define PIN_SD_CLK  46
#define PIN_SD_MOSI 47

#define PIN_MASK_GB_A0 (1 << PIN_GB_A0)
#define PIN_MASK_GB_A14 (1 << PIN_GB_A14)
#define PIN_MASK_GB_A15 (1 << PIN_GB_A15)

#define PIN_MASK_GB_RD (1 << PIN_GB_RD)
#define PIN_MASK_GB_WR (1 << PIN_GB_WR)
#define PIN_MASK_GB_CS (1 << PIN_GB_CS)

#define PIN_MASK_MBC_A0 (1 << PIN_MBC_A0)
#define PIN_MASK_MBC_A1 (1 << PIN_MBC_A1)
#define PIN_MASK_MBC_A2 (1 << PIN_MBC_A2)
#define PIN_MASK_MBC_A3 (1 << PIN_MBC_A3)
#define PIN_MASK_MBC_A4 (1 << PIN_MBC_A4)
#define PIN_MASK_MBC_A5 (1 << PIN_MBC_A5)
#define PIN_MASK_MBC_A6 (1 << PIN_MBC_A6)
//MBC_A7 and MBC_A8 are not connected in V1
#define PIN_MASK_MBC_A7 (1 << PIN_MBC_A7)
#define PIN_MASK_MBC_A8 (1 << PIN_MBC_A8)

#define PIN_MASK_MEM_CE (1 << PIN_MEM_CE)
#define PIN_MASK_MEM_OE (1 << PIN_MEM_OE)
#define PIN_MASK_MEM_WE (1 << PIN_MEM_WE)

#define PIN_MASK_GB_D0 (1 << PIN_GB_D0)
#define PIN_MASK_GB_D1 (1 << PIN_GB_D1)
#define PIN_MASK_GB_D2 (1 << PIN_GB_D2)
#define PIN_MASK_GB_D3 (1 << PIN_GB_D3)
#define PIN_MASK_GB_D4 (1 << PIN_GB_D4)
#define PIN_MASK_GB_D5 (1 << PIN_GB_D5)
#define PIN_MASK_GB_D6 (1 << PIN_GB_D6)
#define PIN_MASK_GB_D7 (1 << PIN_GB_D7)

#define PIN_MASK_BUS_EN (1 << PIN_BUS_EN)

#define PIN_MASK_GB_RST (1 << PIN_GB_RST)
#define PIN_MASK_RUMBLE (1 << PIN_RUMBLE)
#define PIN_MASK_SDA (1 << PIN_SDA)
#define PIN_MASK_SCL (1 << PIN_SCL)
#define PIN_MASK_SD_MISO (1 << PIN_SD_MISO)
#define PIN_MASK_SD_CS (1 << PIN_SD_CS)
#define PIN_MASK_SD_CLK (1 << PIN_SD_CLK)
#define PIN_MASK_SD_MOSI (1 << PIN_SD_MOSI)

#define MEMCHIP_SIZE (2 * 1024 * 1024)

void hwInit();

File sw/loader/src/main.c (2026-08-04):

#include <stdint.h>

uint8_t execCommand(uint8_t);
uint8_t execQuickboot(uint8_t);
void clearScreen(void);
void printStr(uint16_t yx, const char* str);
void updateJoypadState(void) __preserves_regs(d, e);
void waitVBlank(void) __preserves_regs(b, c, d, e, h, l);
extern uint8_t JoypadState;
extern uint8_t JoypadPressed;
#define PADF_DOWN   0x80
#define PADF_UP     0x40
#define PADF_LEFT   0x20
#define PADF_RIGHT  0x10
#define PADF_START  0x08
#define PADF_SELECT 0x04
#define PADF_B      0x02
#define PADF_A      0x01

void strcpy(char* dst, char* src)
{
    while(*src) {
        *dst++ = *src++;
    }
    *dst = 0;
}

char tempBuffer[32];

void main(void)
{
    printStr(0, "Loading file list...");
    execCommand(0x01); //List files
    *((uint8_t*)0x4000) = 0x00; // Switch to bank 0
    printStr(0, "                    ");

    uint8_t* ptr = (uint8_t*)0xA000;
    uint16_t pos = 1;
    while(*ptr) {
        uint8_t bank = ptr[1];
        char* str_addr = *(char**)&ptr[2];
        *((volatile uint8_t*)0x4000) = bank; // Switch to bank containing filename
        printStr(pos, str_addr);
        *((volatile uint8_t*)0x4000) = 0x00; // Switch to bank 0
        ptr += 4;
        pos += 0x100;
    }
    pos = 0;
    printStr(pos, ">");
    while(1) {
        waitVBlank();
        updateJoypadState();
        if (JoypadPressed & PADF_DOWN) {
            if (((char*)0xA000)[(pos + 1) * 4]) {
                printStr(pos << 8, " ");
                pos += 1;
                printStr(pos << 8, ">");
            }
        }
        if (JoypadPressed & PADF_UP) {
            if (pos > 0) {
                printStr(pos << 8, " ");
                pos -= 1;
                printStr(pos << 8, ">");
            }
        }
        if (JoypadPressed & PADF_A) {
            uint8_t bank = *(char*)(0xA001 + pos * 4);
            char* str_addr = *(char**)(0xA002 + pos * 4);
            *((uint8_t*)0x4000) = bank; // Switch to bank with filename
            strcpy(tempBuffer, str_addr);
            *((uint8_t*)0x4000) = 0x0F; // Switch to bank 15
            strcpy((char*)0xA000, tempBuffer);
            printStr(0, "Loading ROM...");
            if (execCommand(0x10)) { //Load file and reset
                // Error
                clearScreen();
                printStr(0x000, "ERROR:");
                printStr(0x100, (const char*)0xBF00);
                do {
                    waitVBlank();
                    updateJoypadState();
                } while((JoypadPressed & (PADF_A | PADF_B)) == 0);
            }
            *((uint8_t*)0x4000) = 0x00; // Switch to bank 0
       }
        if (JoypadPressed & PADF_START) {
            uint8_t bank = *(char*)(0xA001 + pos * 4);
            char* str_addr = *(char**)(0xA002 + pos * 4);
            *((uint8_t*)0x4000) = bank; // Switch to bank with filename
            strcpy(tempBuffer, str_addr);
            *((uint8_t*)0x4000) = 0x0F; // Switch to bank 15
            strcpy((char*)0xA000, tempBuffer);
            execQuickboot(0x11); // Load quickboot
            *((uint8_t*)0x4000) = 0x00; // Switch to bank 0
       }
    }
}

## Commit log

2026-05-26 Add WIP SpiderCart electronics.
    [SpiderCart.kicad_pcb, SpiderCart.kicad_sch, gb_cart.scad]
2026-05-26 Add I2C extension pins, and SWD pins
    [SpiderCart.kicad_pcb, SpiderCart.kicad_sch]
2026-05-27 Add V1 text
    [SpiderCart.kicad_pcb]
2026-05-28 Add pin mapping
2026-06-06 i2c scan.
2026-06-06 Correct issues found in V1 production. I2C pullups where pulldowns, USB D- and D+ where swapped.
    [SpiderCart.kicad_pcb, SpiderCart.kicad_sch]
2026-06-09 small fixes on firmware, not fully tested yet.
    [main.cpp]
2026-06-09 Update shell model to fit the V1 PCB
    [gb_cart.scad]
2026-06-09 Fix MBC simulator not setting right pins
    [main.cpp]
2026-06-10 Fix PIO programs for data bus read/write
    [main.cpp]
2026-06-15 Improved cart case model.
    [gb_cart.scad]
2026-06-20 Set the SPI frequency to 10mhz after SD initialization is complete to much faster load roms
2026-06-21 untested sav file saving (missing diskio part)
    [main.cpp]
2026-06-21 Update on case model. untested SD write implementation
    [gb_cart.scad]
2026-06-22 Fix some compile warnings.
    [hwtest.cpp]
2026-06-22 Add disconnected USB storage device.
2026-06-22 Small P8 improvement. Small case update
    [gb_cart.scad]
2026-06-22 Put in the framework to support the RTC
2026-06-23 Fix SRAM write reliability issue.
    [mbc.cpp, pins.cpp]
2026-06-23 Update case, update readme.
    [gb_cart.scad]
2026-06-23 Make USB inset in cartridge.
    [gb_cart.scad]
2026-06-23 p8 printh
2026-06-26 WIP better error reporting.
    [main.asm, main.c, mbc.cpp]
2026-06-27 Add support for some special chars and for short hand print.
2026-06-30 Fix the wrong FET in V1 design
    [SpiderCart.kicad_pcb, SpiderCart.kicad_sch]
2026-07-01 implement a fake reset in the emulator, bad but mostly okish.
    [mbc.cpp]
2026-07-04 Mostly fix map() not using camera correctly. Fix tostr. Add stat() mostly placeholder and fillp placeholder.
2026-07-04 button repeats.
2026-08-04 MBC7 not working yet, I guess this is too slow...
    [mbc.cpp]
2026-08-05 Working MBC7 accelermeter, but not working eeprom yet.
    [mbc.cpp]
